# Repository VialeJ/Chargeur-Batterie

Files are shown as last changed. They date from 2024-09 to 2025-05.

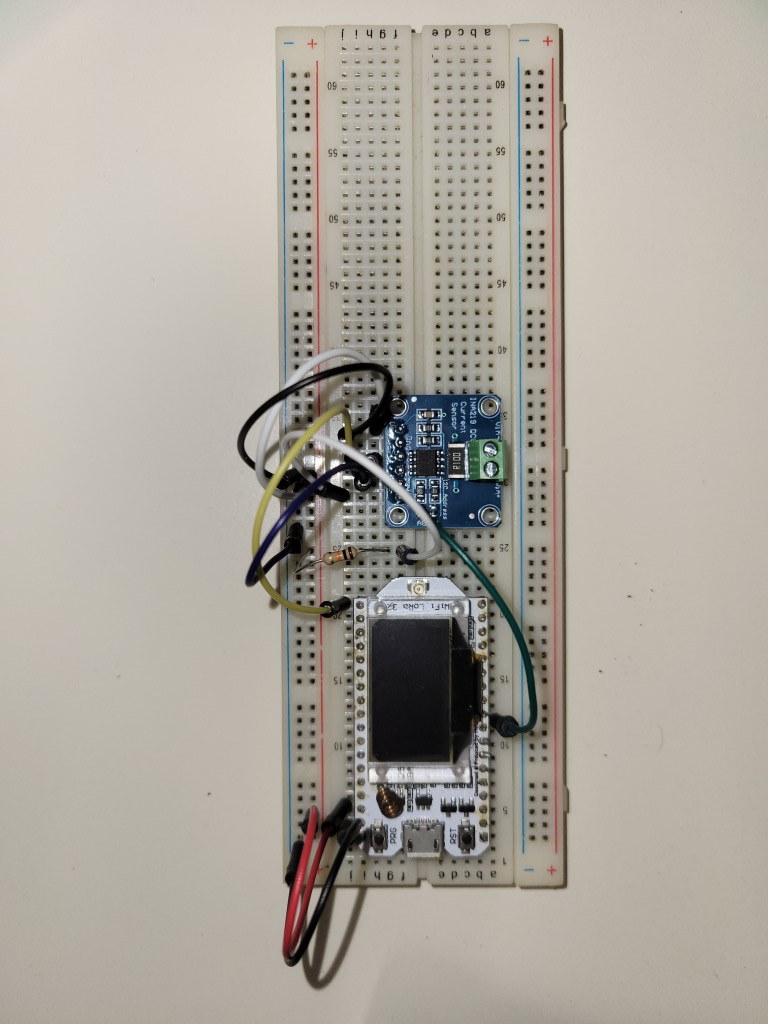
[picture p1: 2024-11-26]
Jeremie/Comptes-rendu/images/20241126_081917_Moyenne.jpg

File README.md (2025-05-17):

# Développement d'un chargeur de batterie

## 1 Cellule entre 5 et 7 Ah
- Posibilité de pouvoir gérer deux cellules dans un second temps

## Différents types de batterie 
- Li-ion (3.6V nom.)
- LiPo (3.7V nom.)
- LiFePO4 (3.2V nom.)

## Systèmes de protection
Protège la cellule contre les surtensions, les soustensions et la chaleur
(Les cellules li-ion utilisées dans ce projet contiennent déjà un BMS)

## Fuel gauge en I2C
Permet la communication des informations de charge et de décharge à un MCU

## 3 types d'alimentation possible:
- USB (5V)
- 12V
- Depuis un panneau solaire 26V (on prendra un Vin max de 28V)

## Package des composants
- CMS
- Eviter un boitier BGA

## Courant de charge de 1A max

## Obtenir le coût le plus faible
Le but est de pouvoir rendre le système reproductible 

## Références des composants
- Ajout de la Datashette des composants utilisés dans le repo git

## Travail à faire :
- Etudier circuits intégrés existants pour la cherge et la fuel gauge et choisir
- INA219 : Mesure de tension, courant et puissance
- Documentation

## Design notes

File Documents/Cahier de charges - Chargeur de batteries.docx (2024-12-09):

# Projet Electronique

# Chargeur de batteries

Cahier des Charges

# Introduction

L’objectif du projet est de créer un chargeur de batterie suivant les caractéristiques énoncées dans ce cahier des charges. Cela permettra d’exploiter des technologies tel que les batteries au lithium, la communication I2C, la gestion d’alimentation ou la conception de schéma électronique.

# Contraintes techniques

## Caractéristiques de la batterie à charger

Pour ce projet, nous utiliserons une cellule de type Lithium-Ion (li-ion) et Lithium-Polymère (LiPo). Il sera par la suite possible d’intégrer la gestion des cellules Lithium Fer Phosphate (LiFePo4) à notre projet. De plus, une piste d’amélioration possible est d’ajouter une cellule à charger à notre projet pour un total de deux cellules en charge en parallèles.

Nous ciblons des cellules d’une capacité comprise entre 5 et 7 Ampères heures (Ah).

Voici une courte description de chaque type de cellules utilisées pour ce projet :

### 1. Li-ion (Lithium-ion)

- Tension : 3,6V nominale, charge jusqu'à 4,2V.
- Méthode de charge : Charge en deux étapes CC-CV (courant constant puis tension constante).
- Avantages : Haute densité énergétique, recharge rapide.
- Inconvénients : Sensible à la surcharge, risque de surchauffe.
- Protection en charge : Utilisation d’un BMS (Battery Management System) pour couper le courant une fois la charge complète atteinte et éviter les surcharges.

### 2. LiPo (Lithium Polymère)

- Tension : 3,7V nominale, charge jusqu'à 4,2V.
- Méthode de charge : Technique CC-CV avec surveillance constante, sensible aux variations.
- Avantages : Légèreté et flexibilité de forme, haute densité énergétique.
- Inconvénients : Fragile, risque de gonflement ou d’inflammation en cas de surcharge.
- Protection en charge : Surveillance renforcée pour maintenir le courant et la tension dans des limites sûres.

### 3. LiFePO4 (Lithium Fer Phosphate)

- Tension : 3,2V nominale, charge jusqu’à 3,65V.
- Méthode de charge : Technique CC-CV, seuils de tension inférieurs à ceux des autres lithiums.
- Avantages : Excellente stabilité thermique, longue durée de vie même sous charge répétée.
- Inconvénients : Densité énergétique plus faible.
- Protection en charge : Le BMS surveille la charge pour éviter toute surcharge, bien que le risque thermique soit faible.

## Modes d’alimentation

Le projet disposera de plusieurs modes d’alimentation distincts, permettant une certaine flexibilité à l’utilisateur. Il faut veiller à fournir la puissance nécessaire à notre circuit pour alimenter nos composants et charger notre cellule. Le courant de charge imposé est de 1A par cellule.

Le chargeur de batterie devra disposer :

- D’une alimentation par USB : Mode d’alimentation 5V, un port USB à définir permettra une connexion plus universelle et simplifiée à notre projet. Attention tout de même à fournir la puissance nécessaire pour charger la cellule et alimenter notre système.
- D’une alimentation par panneau solaire : Un panneau solaire doit pouvoir être connecté à notre système, ainsi nous pourrons charger nos batteries en journée. La tension maximale délivrée par le panneau solaire est de 28V. Il faut prendre garde à la variation de la tension au cours de la journée.
- D’une alimentation par 12V : Une alimentation externe de 12V doit aussi pouvoir être connectée à notre chargeur de batterie.

## Protection et contrôle

Le projet devra intégrer un système de contrôle d’état de la charge, pour cela on utilisera un fuel gauge connectée en I2C à une carte ESP32 intégrant un écran. Ainsi nous pourrons contrôler, le courant de charge, le taux de charge et la tension de la cellule. Ce composant ouvrira de nouvelles possibilités telles qu’afficher le temps depuis lequel la cellule charge ou le temps restant.

Pour ce qui est de la partie protection, les cellules lithium étant des cellules très sensibles, il faut un système fiable et capable de prévenir d’éventuels problèmes. Dans notre cas, nous devrons utiliser un composant de gestion de charge qui sera capable de :

- Protéger notre cellule contre la surcharge en interrompant la charge lorsque la tension maximale est atteinte.
- Protéger notre cellule contre la surintensité pour éviter les courants excessifs.
- Permuter les modes de charges au bon moment (passer d’une charge en courant constant à une charge en tension constante).
- Possibilité d’ajouter un contrôle de la température pouvant nous aider à couper la charge en cas de surchauffe.

## Exigences Techniques

Composants CMS principalement :

- La plupart des composants du chargeur devront être en technologie CMS (Composants Montés en Surface) afin de minimiser l’encombrement du circuit, simplifier l’assemblage et réduire les coûts de fabrication.

Exclusion des boîtiers BGA :

- Les composants utilisant des boîtiers BGA (Ball Grid Array) devront être évités en raison des défis liés à leur assemblage et à leur accessibilité au cas où nous souhaiterions réaliser des mesures.

## Contraintes de Conception

Coût minimal :

- Le chargeur devra être conçu de manière à minimiser le coût global tout en respectant les exigences techniques et fonctionnelles.
- Les choix des composants et des matériaux devront favoriser les alternatives low-cost, sans compromettre la sécurité et la qualité.

Reproductibilité :

- Le système doit être conçu pour être reproductible à grande échelle, avec des composants faciles à trouver sur le marché et une documentation claire pour l'assemblage et l’utilisation.
- La conception devra être modulaire et flexible, permettant des modifications ou améliorations futures sans révision complète.

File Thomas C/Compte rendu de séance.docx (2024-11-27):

# Compte rendu de séance

WATTY BATTERY

Thomas Cougouluegne

Séance 1: Choix des groupes, Discussion du contenu du cahier des charges et limites du projet.

Séance 2: Définition en groupe du cahier des charges du projet, définition des sujets de travail de chacun, recherches sur le fonctionnement et les valeurs critiques des circuits fuel gauge.

Séance 3: Recherche de composant fuel gauge, et comparaison des options disponibles.

Recherche arrêtée sur le TI BQ27411DRZT-G1A ;

Boitier 12 VDFN disponibles, soudable sans soucis à la main, 1 cellule,

Tech Li-ion, communication des données en I²C.

Question de la charge d’éléments en parallèle ; attention au déséquilibrage de lignes. Pose la question du besoin d’un équilibreur de ligne ? Après révision des fonctions du circuit de charge, l’équilibrage de lignes sera maitrisé par le circuit.

Séance 4: Lecture et création du schéma avec les recommandations de Texas Instrument pour

le BQ27411. Uniquement deux condensateur a mettre en place autour du CI

(entre Vdd et Vss / entre BAT et Vss).

Mettre en place le système de detection de batterie. Quand une batterie est en charge, la pin BIN doit recevoir un signal à l’état bas (environ 0V). Pour ce, système de pull-up à Vdd de la pin BIN (1,8 MOhms) et connexion a la sortie de la batterie via thermistance pour qu’à la connexion de la batterie la pin BIN soit pull-down. (10kOhms).

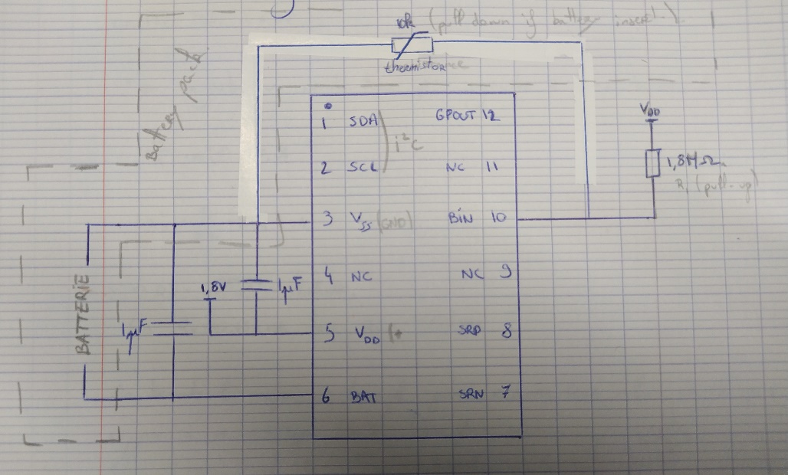
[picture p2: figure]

Possible besoin d’un régulateur de tension à 1.8V pour l’alim de la fuel gauge.

Vu voltag reg chez les distribs, disponibles à l’unité a faible cout, verifier si diode ou voltage divider possible (attention stab si V div).

Début du schéma sous kicad pour mise en commun et commande.

Séance 5 :

Schéma fait sous kicad et révisé, pin BIN réajustée selon notre besoin.

Recherche de régulateur de tension pour le schéma Circuit de charge.

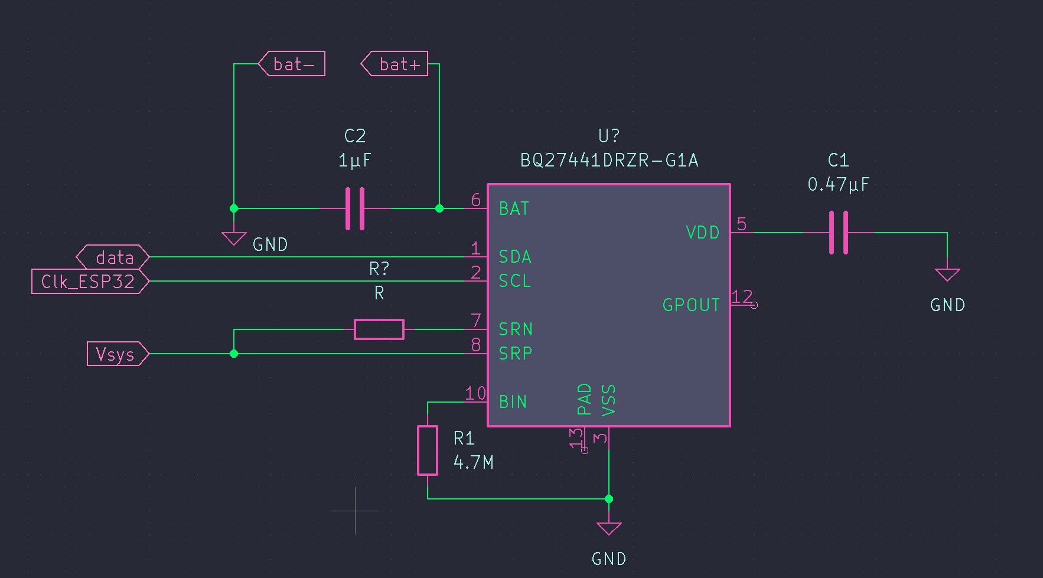
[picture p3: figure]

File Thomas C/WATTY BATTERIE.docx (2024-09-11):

30V -> buck -> 5V LMxxxx

12V -> buck -> 5V Même buck pour 30V et 12V ? (verif si pb quand 30 et 12 actifs simultané)

5V -> 5V

Trames I2C pour communiquer « fuel gauge » et « tension de sortie de panneau »

Pour gestion I2C, MCU mieux que

Protection court-circuit sera donné par M.Peter dans les prochaines séances. (a mettre en serie avec la sortie vers batterie)

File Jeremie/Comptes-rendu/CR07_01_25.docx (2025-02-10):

On fait quoi ?

Rédaction d’un protocole de test pour le chargeur

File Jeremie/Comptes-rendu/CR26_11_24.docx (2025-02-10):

Changement de board sur Arduino IDE pour régler le problème (Pas la bonne séléctionnée au préalable). Le programme s’upload sur la carte

Le pinout utilisé est le suivant

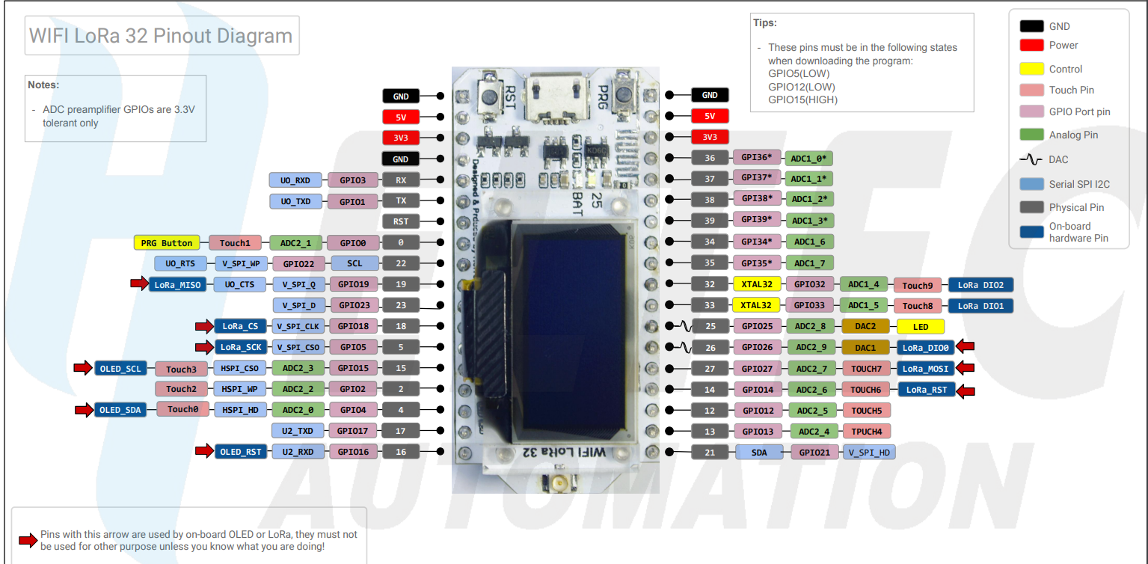
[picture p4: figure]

Tests : On branche une résistance de 10kOhm en série pour effectuer des tests, comme ceci :

La ligne + est reliée au 3.3V, la ligne – au GND. La résistance va au Vin+, le Vin- va au GND. SDA et SCL sont connectés à leurs branches respectives.

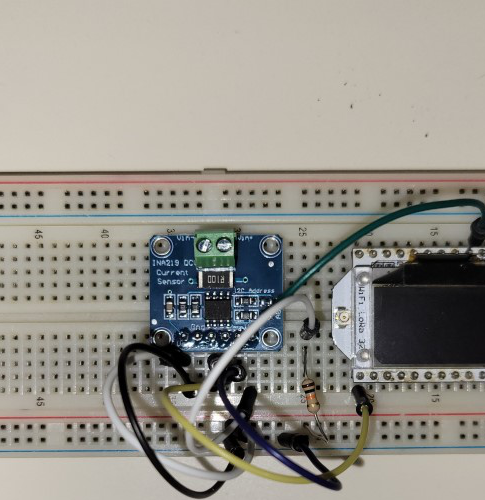
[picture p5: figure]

On obtient en mesures avec le code getinfos :

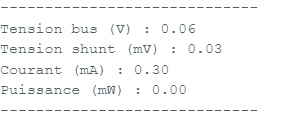
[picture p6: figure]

Ce qui semble cohérent comme on a placé la resistance avant le capteur.

En changeant son emplacement, connectant la résistance au GND, on obtient :

Ce qui est aussi cohérent, comme on mesure la tension aux bornes de la résistance.

On peut faire un simple pont diviseur pour vérifier plus concrètement :

Avec deux résistances de 10kOhm, le courant semble trop faible pour que le capteur le detecte correctement. On met alors des résistances plus faibles pour augmenter le courant. Avec deux résistances de 1kOhm, on obtient :

Ce qui est cohérent avec les valeurs de résistances et de la tension envoyée. On envoie 3.3 depuis l’ESP dans un pont diviseur entre deux résistances de 1kOhm, donc ~1.5V aux bornes de chaque résistance

Amélioration du code pour interroger la fuel gauge (Quand on l’aura reçue), sur l’état de charge et le votlage.

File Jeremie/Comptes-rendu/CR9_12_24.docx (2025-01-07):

Recherches CN3761

Input range : 4.5V – 28V

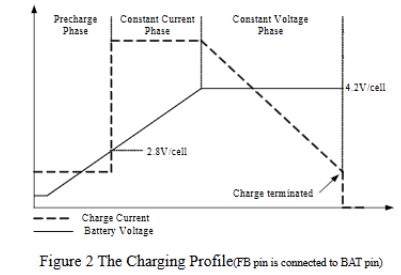
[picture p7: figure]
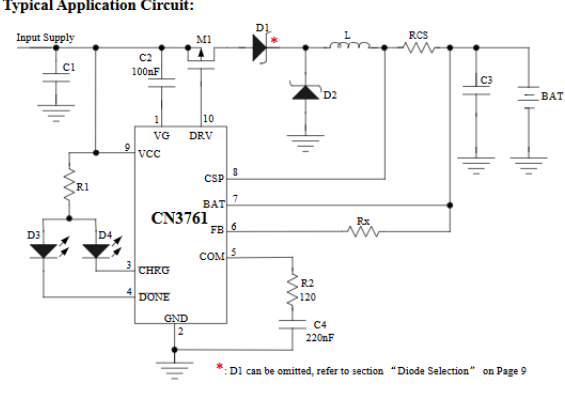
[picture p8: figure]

DS6521 : Max input voltage à 24V donc on l’exclut des possibilités de régulateur de charge

Optimisation du temps

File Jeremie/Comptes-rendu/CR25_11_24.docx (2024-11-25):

25/11/24 : Création d’un premier code de test, branchements de l’esp sur bread-board

Problème d’upload du programme sur l’esp

Branché au PC, la plaque n’explose pas, ce qui est un point positif.

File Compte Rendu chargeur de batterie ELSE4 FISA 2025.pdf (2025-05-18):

Faucherre Thomas
Cougouluegne Thomas
Viale Jérémie

# Projet Electronique Chargeur de batteries

# Introduction :

L’objectif du projet est de créer un chargeur de batterie suivant les caractéristiques énoncées dans ce cahier des charges joint. Cela permettra d’exploiter des technologies telles que les batteries au lithium, la communication I2C, la gestion d’alimentation ou la conception de schéma électronique.

# Cahier des charges :

## Contraintes techniques

### Caractéristiques de la batterie à charger

Pour ce projet, nous utiliserons une cellule de type Lithium-Ion (li-ion) et Lithium-Polymère (LiPo). Il sera par la suite possible d’intégrer la gestion des cellules Lithium Fer Phosphate (LiFePo4) à notre projet. De plus, une piste d’amélioration possible est d’ajouter une cellule à charger à notre projet pour un total de deux cellules en charge en parallèle.

Nous ciblons des cellules d’une capacité comprise entre 5 et 7 Ampères heures (Ah).

Voici une courte description de chaque type de cellules utilisées pour ce projet :

1. Li-ion (Lithium-ion)
- Tension : 3,6V nominale, charge jusqu'à 4,2V.
- Méthode de charge : Charge en deux étapes CC-CV (courant constant puis tension constante).
- Avantages : Haute densité énergétique, recharge rapide.
- Inconvénients : Sensible à la surcharge, risque de surchauffe.
- Protection en charge : Utilisation d’un BMS (Battery Management System) pour couper le courant une fois la charge complète atteinte et éviter les surcharges.

2. LiPo (Lithium Polymère)
- Tension : 3,7V nominale, charge jusqu'à 4,2V.
- Méthode de charge : Technique CC-CV avec surveillance constante, sensible aux variations.
- Avantages : Légèreté et flexibilité de forme, haute densité énergétique.
- Inconvénients : Fragile, risque de gonflement ou d’inflammation en cas de surcharge.
- Protection en charge : Surveillance renforcée pour maintenir le courant et la tension dans des limites sûres.
3. LiFePO4 (Lithium Fer Phosphate)
- Tension : 3,2V nominale, charge jusqu’à 3,65V.
- Méthode de charge : Technique CC-CV, seuils de tension inférieurs à ceux des autres lithiums.
- Avantages : Excellente stabilité thermique, longue durée de vie même sous charge répétée.
- Inconvénients : Densité énergétique plus faible.
- Protection en charge : Le BMS surveille la charge pour éviter toute surcharge, bien que le risque thermique soit faible.

### Modes d’alimentation

Le projet disposera de plusieurs modes d’alimentation distincts, permettant une certaine flexibilité à l’utilisateur. Il faut veiller à fournir la puissance nécessaire à notre circuit pour alimenter nos composants et charger notre cellule. Le courant de charge imposé est de 1A par cellule.

Le chargeur de batterie devra disposer :

- D’une alimentation par USB : Mode d’alimentation 5V, un port USB à définir permettra une connexion plus universelle et simplifiée à notre projet. Attention tout de même à fournir la puissance nécessaire pour charger la cellule et alimenter notre système.
- D’une alimentation par panneau solaire : Un panneau solaire doit pouvoir être connecté à notre système, ainsi nous pourrons charger nos batteries en journée. La tension maximale délivrée par le panneau solaire est de 28V. Il faut prendre garde à la variation de la tension au cours de la journée.
- D’une alimentation par 12V : Une alimentation externe de 12V doit aussi pouvoir être connectée à notre chargeur de batterie.

### Protection et contrôle

Le projet devra intégrer un système de contrôle d’état de la charge, pour cela on utilisera un fuel gauge connectée en I2C à une carte ESP32 intégrant un écran. Ainsi nous pourrons contrôler, le courant de charge, le taux de charge et la tension de la cellule. Ce composant ouvrira de nouvelles possibilités telles qu’afficher le temps depuis lequel la cellule charge ou le temps restant.

Pour ce qui est de la partie protection, les cellules lithium étant des cellules très sensibles, il faut un système fiable et capable de prévenir d’éventuels problèmes. Dans notre cas, nous devrons utiliser un composant de gestion de charge qui sera capable de :

- Protéger notre cellule contre la surcharge en interrompant la charge lorsque la tension maximale est atteinte.
- Protéger notre cellule contre la surintensité pour éviter les courants excessifs.
- Permuter les modes de charges au bon moment (passer d’une charge en courant constant à une charge en tension constante).
- Possibilité d’ajouter un contrôle de la température pouvant nous aider à couper la charge en cas de surchauffe.

## Exigences Techniques

Composants CMS principalement :

- La plupart des composants du chargeur devront être en technologie CMS (Composants Montés en Surface) afin de minimiser l’encombrement du circuit, simplifier l’assemblage et réduire les coûts de fabrication.

Exclusion des boîtiers BGA :

- Les composants utilisant des boîtiers BGA (Ball Grid Array) devront être évités en raison des défis liés à leur assemblage et à leur accessibilité au cas où nous souhaiterions réaliser des mesures.

## Contraintes de Conception

Coût minimal :

- Le chargeur devra être conçu de manière à minimiser le coût global tout en respectant les exigences techniques et fonctionnelles.
- Les choix des composants et des matériaux devront favoriser les alternatives low-cost, sans compromettre la sécurité et la qualité.

Reproductibilité :

- Le système doit être conçu pour être reproductible à grande échelle, avec des composants faciles à trouver sur le marché et une documentation claire pour l'assemblage et l’utilisation.

La conception devra être modulaire et flexible, permettant des modifications ou améliorations futures sans révision complète.

Maintenant que le contexte global du projet est posé, nous pouvons commencer à détailler chaque partie, en commençant par le circuit de gestion de charge, puis le circuit d’alimentation, et terminer par la gestion du code permettant de valider le fonctionnement de notre chargeur.

# Partie Circuit de gestion de charge :

Cette partie concerne le choix et le design de l’écosystème autour du composant principal de notre projet. Ce circuit a pour but la régulation de la tension et du courant de charge de la batterie. A noter que ce composant ne gère pas la décharge de la batterie, l’utilisateur pourra se brancher directement sur les bornes de la batterie. D’après le cahier des charges, nous voulons un composant qui peut prendre en entrée une tension maximale de 28V (adapté au solaire), chargé notre batterie à 1 A maximum, charger une seule cellule et gérer dans un premier temps la charge des cellules lithium ion et lithium polymère.
Pour sélectionner le bon composant en fonction des caractéristiques du cahier des charges, nous avons utilisé un tableau comparatif des références de composant trouvées sur internet.

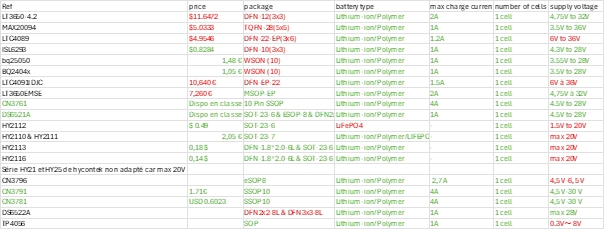
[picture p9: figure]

Figure 1 - Tableau comparatif des circuits de charge

Cette méthode nous permet selon nos critères de choisir correctement notre circuit. La principale contrainte est la tension d’entrée maximum de 28V. En conclusion de ce tableau, nous avons retenu deux circuits : le DS6521 et le CN3761. Ces composants ont l’avantage d’être disponibles en salle de cours.
Nous avons donc choisi le DS6521 de chez DSTECH, ce circuit est dans un package ESOP-8 ce qui respecte la contrainte de package CMS non BGA. Ce circuit possède les caractéristiques suivantes :
- Tension d'entrée de 28V ; avec protection contre les surtensions à 6V
- Précision de la tension de charge à 1 %
- Courant de charge programmable de 50 mA à 1 A
- Régulation thermique à 125°C
- Courant de fin de charge programmable de 5 mA à 100 mA
- Courant de précharge fixe à ISET / 10
- Fonctionnement conforme à la plage JEITA via NTC batterie – 1/2 du courant de charge rapide à froid, et 4,05 V à chaud
- Courant de fuite de la batterie très faible : 0,1 µA
- Fonction de protection contre la connexion inversée de la batterie

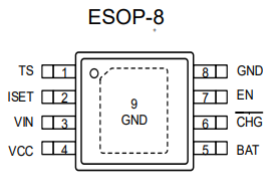
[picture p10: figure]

Figure 2 - Package et brochage du DS6521

Il nous a ensuite fallu réaliser le schéma autour de ce composant. Pour cela nous allons nous inspirer du schéma fourni par le fabricant dans la datasheet :

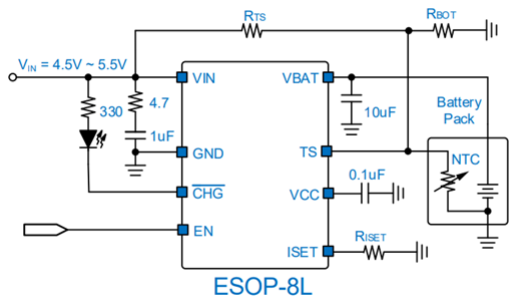
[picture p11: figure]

Figure 3 - Schéma classique

Dans un premier temps, nous utilisons un filtrage à l’entrée Vin : la résistance de 4,7 Ω et le condensateur de 1 µF forment un filtre RC qui stabilise la tension d’entrée. La résistance limite les courants d’appel lors de la mise sous tension. Le condensateur filtre les bruits et pics de tension parasites. Ensemble, ils protègent le circuit et assurent une alimentation plus propre. Ce montage améliore la fiabilité du système.
La broche CHG barre est à l’état haut lorsque la batterie ne charge pas, et passe à l’état bas lorsque la batterie charge. Contrairement au design recommandé, nous n’allons pas placer la led avec la résistance de 330 Ohm sur l’entrée Vin, mais plutôt sur la broche VCC. Le VCC du DS6521 est une source de tension 5V, ainsi si la tension d’entrée varie la résistance sera toujours bien dimensionnée car positionnée sur le VCC de 5V.

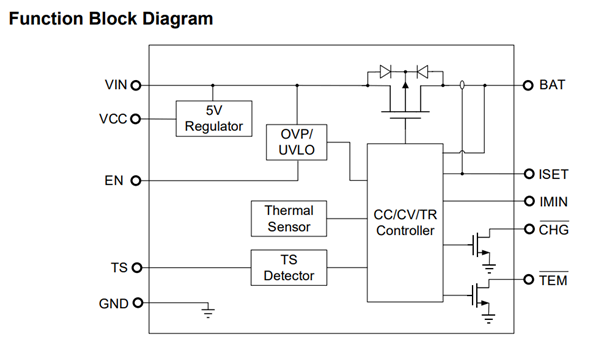
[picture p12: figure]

Figure 4 - Diagramme bloc du DS6521

La broche EN sert à l’activation du circuit, on la met à 5V lorsqu’on veut activer le circuit, cependant nous voulons toujours activer le DS6521 donc nous allons relier ce pin au 5V du VCC.
La broche ISET régule de courant de charge selon ces équations :

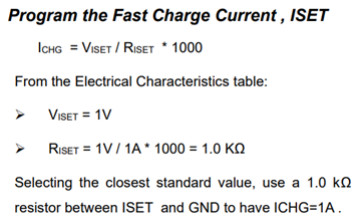
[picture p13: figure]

Figure 5 - calcul de ISET

Ainsi nous souhaitons une charge de 1A, donc nous allons utiliser une résistance de 1kOhm pour ce projet. Pour la phase de test, nous utilisons une batterie de plus faible capacité et donc avec un courant de charge réduit, ainsi nous allons diviser par trois cette charge (330 mA) donc nous utiliserons selon les calculs une résistance 3 fois plus grande (soit 3 kOhms).
Pour la partie gestion de température, notre projet intègre des capteurs de températures qui permettent de monitorer la charge. Deux capteurs seront présents, un sur le DS6521 pour gérer la charge, et un sur le circuit fuel gauge qui permettra d’avoir une surveillance de la température en temps réel lors de la décharge. Pour la partie DS6521, la broche TS est réservée à l’utilisation d’une thermistance (NTC) qui est une résistance variant avec la différence de température. Voici les caractéristiques de la datasheet sur le capteur de température :

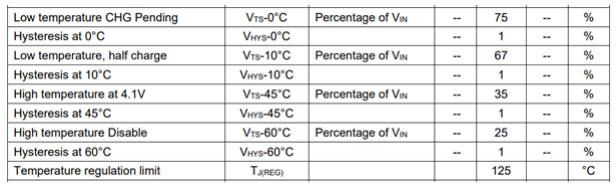
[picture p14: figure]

Figure 6 - NTC caractéristiques en tension

La température est détectée en fonction du rapport de la tension TS sur la tension d’entrée Vin. Ainsi, nous avons besoin de créer un pont diviseur comme indiqué dans le schéma type du constructeur. Dans le tableau plus haut on remarque que la température normale d’utilisation est atteinte pour 50% de Vin en moyenne, il faut donc diviser par deux Vin, pour cela on va réaliser un pont diviseur de tension avec comme indiqué dans le schéma plus haut RBOT à 10kOhm (en parallèle de la NTC) et donc une résistance RTS équivalente à la NTC et RBOT en parallèle, soit 5 kOhms. Ainsi pour la température moyenne d’utilisation on est à 50% de Vin.
On notera d’après la datasheet qu’en dessous de 0°C (VTS>0.75Vin) la charge se coupe et se met en attente, entre 0 et 10°C (0.67Vin<VTS<0.75Vin) on charge avec un courant divisé par deux, entre 45°C et 10°C (0.35Vin<VTS<0.67Vin) on est en mode de charge normal, entre 45°C et 60°C (0.25Vin<VTS<0.35Vin) on charge à 4.1V au lieu de 4.2V et enfin au-dessus de 60°C (VTS<0.25Vin) On désactive de circuit intégré.
On ajoute aussi des condensateurs en entrée (sur Vin en série avec une résistance) et sur les pins d’alimentation tel que CVV et Bat+. Ces Condensateurs servent au filtrage des potentielles parasites de tensions ainsi qu’au découplage des sources d’énergies, c’est-à-dire qu’ils prennent le relais comme source de tension lors des forts appels de courant.

Voici finalement notre version du schéma du DS6521 et de son écosystème :

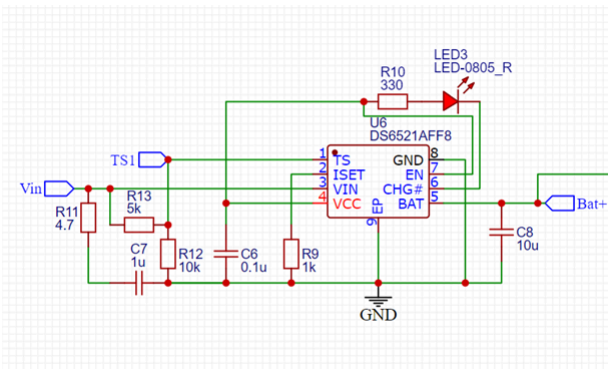
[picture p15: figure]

Figure 7 - Notre schéma du DS6521

Après de nombreux tests sur notre circuit, il s’est avéré que nous avons commis une erreur dans le choix du composant de charge. En effet l’intitulé de la datasheet semble trompeur. Il y est mentionné une tension d’entrée de 28V, mais ce n’est en réalité pas le cas.

Figure 8 - Intitulé datasheet DS6521

Figure 9 - Extrait des caractéristiques du DS6521

La datasheet est une version chinoise traduite en anglais, ce qui peut être la source de l’erreur, mais ici le DS6521 fonctionne jusqu’à 6V en entrée et est protégé pour les surtensionsjusqu’à 28V. Cela rend notre projet inapte pour les conceptionsalimentée par panneau solaire, et donc lui fait perdre son intérêt principal. Cependant nous pouvons tout de même réaliser des tests avec des tensions de 5V.

# Partie Circuit Fuel Gauge :

Cette partie concerne le choix et le design de l’écosystème autour du composant fuel gauge de notre projet. Ce circuit a pour but de mesurer l’énergie dans la batterie afin de superviser la batterie de manière cohérente.
De nombreuses solutions fuel gauge sont aujourd’hui disponibles sur le marché, toutefois le cahier des charges implique de trouver une solution gérant les technologies LiPO, Li-ion, . Mon premier choix s'est alors porté sur le Texas instrument BQ25441-G1 qui est une solution dimensionnée pour notre type d’application single-cell sans trop de surplus. Toutefois, ce composant n’étant disponible que dans les packages VSON (pitch de 0,4mm), cette solution à été abandonnée car jugée trop difficile à monter sur le pcb.

Alors après de longues recherches infructueuses pour trouver un composant équivalent correspondant au critère de pitch et package, nous nous sommes résiliés à utiliser le Texas instrument BQ34Z100-G1. Composant fuel gauge plus avancé pour n-cell (Li-ion, LiFePO4, et plus) qui malgré son surdimensionnement est un des rares seul présentant toutes les caractéristiques recherchées.

Les fonctions utiles pour nous seront :

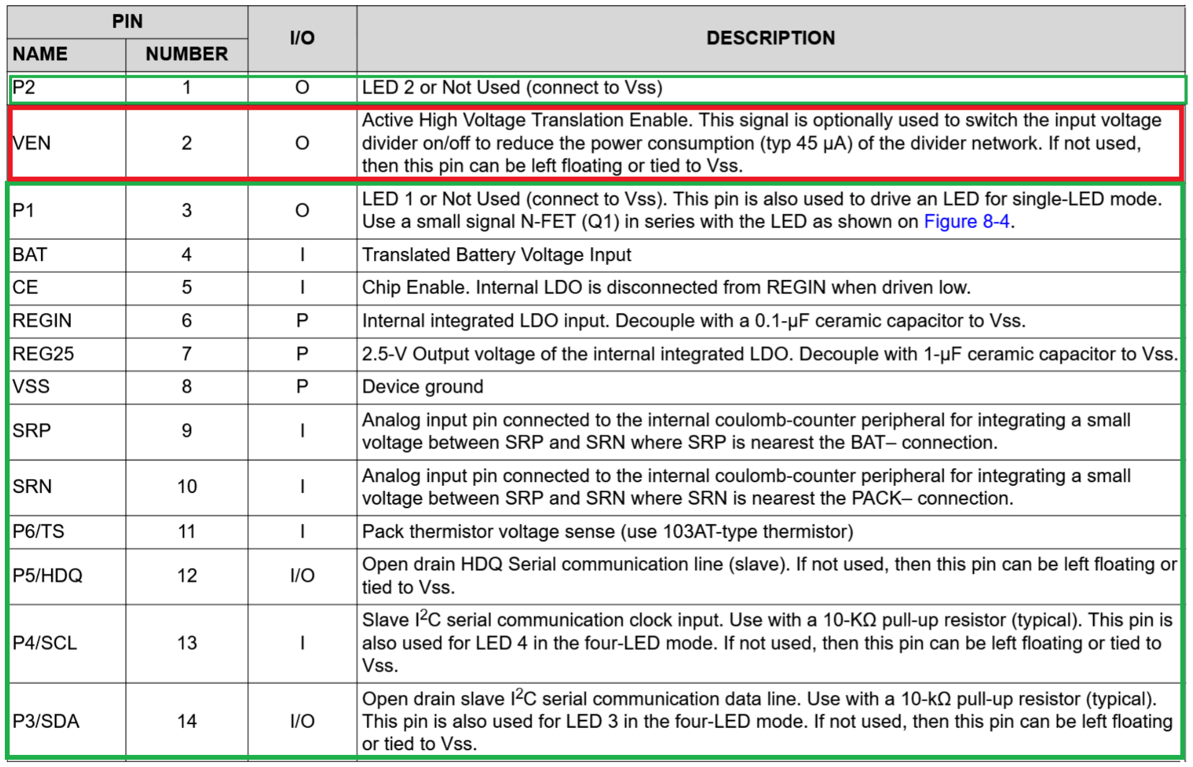
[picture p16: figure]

Figure 10 - Fonctions utiles Fuel Gauge (encadrées en vert)

Il faut donc dans notre schéma intégrer les composants nécessaires au bon fonctionnement de ces dernières tels que :

1. Le montage de R1; R2; U2 -> permet de pull-up SDA à 3.3V
Sachant que 3.3V ne sont présents nulle part ailleurs sur le schéma pour un pull-up direct, d’où la mise en place de ce level converter.
Rappel: pour fonctionner tout bus I²C doit être par défaut à 3.3V et communique en changeant l’état de la ligne via pull-downs.
2. Le montage de R3; R4; U1 -> permet de pull-up à 3.3V SCL comme 1.
3. Le montage de U3; U4; R8; R14 -> permet l’allumage de LEDs de fonctionnement contrôlées par les signaux P1 et P2.
Les résistances sont dimensionnées pour maîtriser le courant nécessaire aux LEDs. Quant aux deux MOS ils permettent de mettre à la masse (ou non) la branche du circuit dont P1 ou P2 est actif pour allumer (ou éteindre) la LED en conséquence.
4. C1 et C2 -> Sont des capacités de découplage qui pour rappel servent à réduire les bruits et interférences dans un circuit.
5. Le montage de R5; R6; R7; C3; C4; C5 -> Permet de transmettre une image des caractéristiques de la batterie à nos pins SRN et SRP.
C’est ce montage qui permet à notre fuel gauge de fonctionner.
R5 est une résistance de shunt
6. R6; R7; C3; C4; C5 forment un filtre passe bas (différentiel) qui permet de réduire les impuretés et bruits sur le signal. Les valeurs sont données par le constructeur.
Il faut que ce montage soit routé avec des pistes différentielles
(de même longueur et propriétés) pour soigner le signal et assurer des valeurs reçues cohérentes. Pour plus de détails voir pages 55 et 56 de la datasheet.

Notre schéma final est donc le suivant :

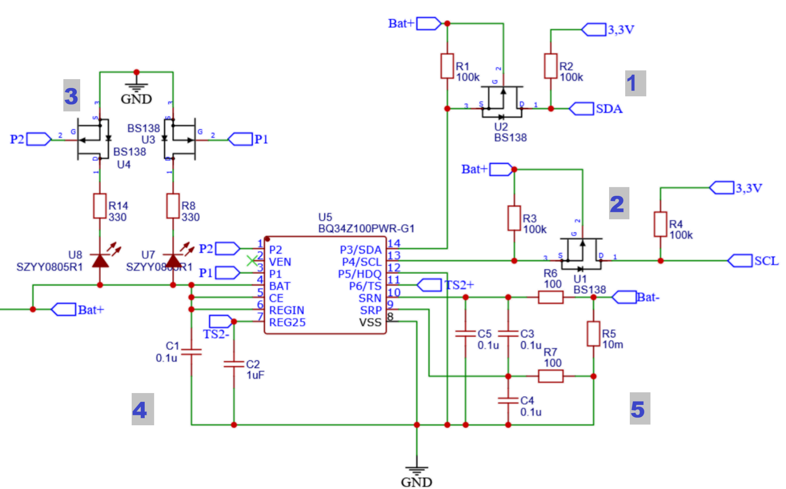
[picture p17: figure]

Figure 11 - Schéma Fuel Gauge

Après les tests sur notre solution la partie fuel gauge marche comme prévu et communique bien en I²C les valeurs nécessaires. Rien ne semble à retoucher sur cette partie.

# Partie codage et tests :

Cette parti concerne l’agencement du code et des fonctionnalités choisies pour valider le fonctionnement du système, il est fait sous arduino et doit fonctionner avec une carte HELTEC Wifi-LoRa v1.
La carte Heltec doit rêtre reliée à un capteur INA-219 et la fuel-gauge précisée dans le chapitre précédent via I2C, donc il est dans un premier temps important d’identifier les broches à utiliser dans ce but :

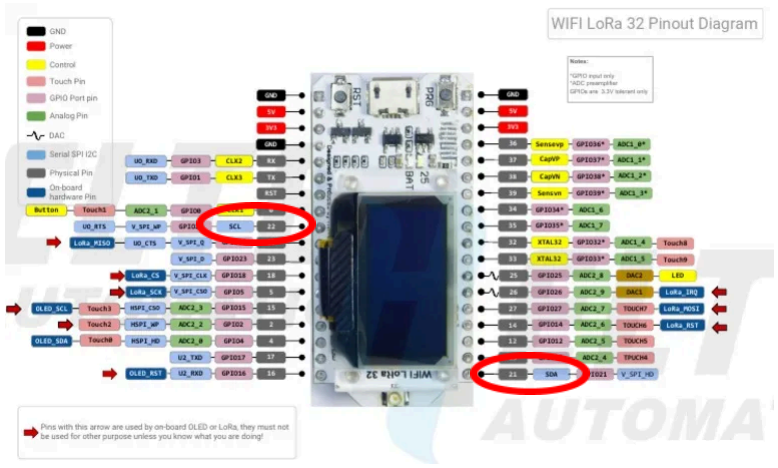
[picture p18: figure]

Figure 12 - Pinout de la carte HELTEC WIFI LoRa 32 v1

Nous utiliserons dans le futur les broches mises en évidence sur la figure 12 pour la communication en I2C.
Passons à la revue du code :
Déclaration des bibliothèques et constantes du programme :
Dans cette partie, on prend deux bibliothèques, Wire, qui est la bibliothèque I2C classique d’Arduino, et une pour l’INA, fournie par Adafruit, qui évite de devoir créer les fonctions d’interrogation de l’INA-219 à la main. Aucune bibliothèque n’est disponible pour la fuel-gauge BQ34Z110, donc pour celui là, il a fallu, dans la datasheet, rechercher quels registres interroger pour obtenir les données voulues.
Plusieurs constantes sont définies pour faciliter l’interrogation de la fuel gauge : les adresses des registres d’état de charge, de tension et de température sont extraites de la documentation du BQ34Z110. Une constante permet aussi d’activer ou non les messages de debug. Deux intervalles de temps sont ensuite définis pour gérer de manière non bloquante la fréquence des mesures : 1000 ms pour le courant et 5000 ms pour les autres données de la fuel gauge. Des variables previousMillis permettent de suivre le temps écoulé.

Fonction sendControlCommand :
Cette fonction permet d’envoyer une commande de contrôle à la fuel gauge via le registre Control() (adresse 0x00). Par exemple, elle est utilisée ici pour envoyer la commande IT_ENABLE (0x0021) qui active le suivi d’impédance. La commande est envoyée en little endian (LSB puis MSB), comme spécifié dans la datasheet. Un message est affiché en mode debug pour confirmer l’envoi.
Cette fonction est utile pour calibrer la fuel gauge, dans un premier cycle de charge/decharge contrôlé, afin qu’elle renvoie des valeurs d’état de charge cohérentes.

Fonctions de lecture I2C :
Deux fonctions sont définies pour lire des données depuis la fuel gauge : readFuelGaugeByte() lit un seul octet (utilisé pour l’état de charge).
readFuelGaugeWord() lit deux octets en little endian (utilisé pour la tension et la température).
Chacune vérifie s’il y a eu une erreur de transmission ou un nombre de données insuffisant. En cas de problème, une valeur d’erreur est renvoyée et un message est affiché si le mode debug est activé.

Fonction updateFuelGauge :
Cette fonction regroupe les différentes lectures de la fuel gauge :
Elle lit l’état de charge (en %), la tension (en millivolts) et la température (en dixièmes de kelvin, convertie ensuite en °C).
Chaque mesure est affichée sur le port série si elle est valide, sinon un message d’erreur est montré.
Une ligne de séparation est imprimée à la fin pour plus de lisibilité.

Fonction setup :
Le port série est initialisé, puis le bus I2C est activé via Wire.begin().
Le capteur INA219 est initialisé à l’aide de la méthode begin() fournie par la bibliothèque Adafruit. En cas d’échec, le programme s’arrête. Sinon, un message confirme la réussite. Après un court délai de stabilisation, la commande IT_ENABLE est envoyée à la fuel gauge pour démarrer la mesure d’impédance.

Fonction loop :
La fonction principale du programme repose sur deux mises à jour non bloquantes, basées sur la fonction millis() :
Toutes les secondes, le courant mesuré par le capteur INA219 est affiché.
Toutes les cinq secondes, les données de la fuel gauge sont lues et affichées via updateFuelGauge().
Cela permet au programme de fonctionner sans pauses inutiles (sans delay()), ce qui est utile pour des systèmes embarqués réactifs.

Passons enfin à l’affichage des tests :

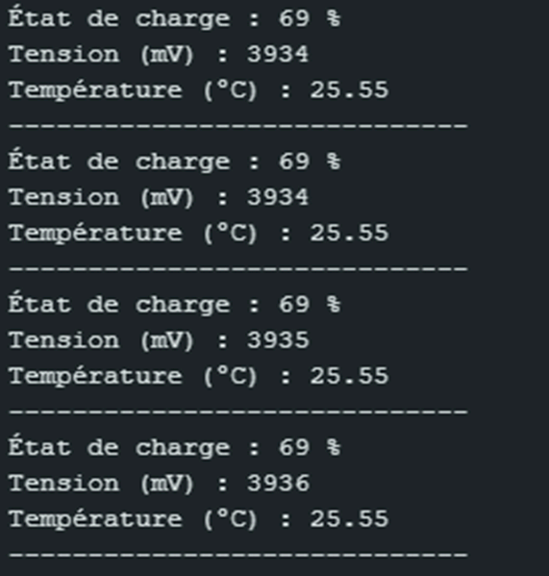
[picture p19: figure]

Figure 13 - Resultats Fuel Gauge

Voici les résultats de la communication avec la fuel Gauge, n’étant pas calibrée, elle renvoie une valeur de State Of Charge (SOC) fausse, mais cohérente, entre 0 et 100%, ce qui est encourageant. La valeur de tension et la température ont pu être confirmées respectivement avec un multimètre et des pointes, et avec un thermomètre.

Pour ce qui est de la communication avec l’INA-219, des tests ont été effectués au premier semestre pour valider le fonctionnement, tests ayant donné les résultats suivants :

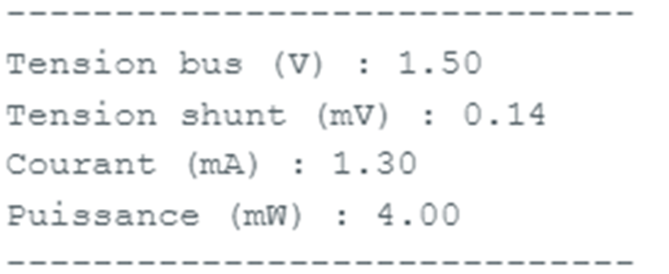
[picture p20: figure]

Figure 14 - Résultats INA-219

L’INA était monté pour mesurer la tension au milieu d’un pont diviseur de tension par 2, fait avec deux résistances de 1k ohm, alimenté par la broche 3.3V de la carte HELTEC, ce qui renvoie des valeurs cohérentes, bien que la valeur de courant semble un peu faible pour 3V qui passent dans 2k ohm, car on attend 1,5 mA, soit une erreur d’environ 13%.

# Pistes d’amélioration :

Notre projet n’a aujourd’hui pas encore la maturité nécessaire pour avoir un usage concret, il nous faut avant améliorer certains points notamment hardware. Voici une liste des points à améliorer :
- Circuit de charge non adapté : Comme précisé auparavant, le circuit de charge DS6521 possède une documentation ambiguë au niveau de sa tension de fonctionnement. Il nous faudra changer de circuit de charge pour en sélectionner un qui puisse fonctionner avec une tension d’entrée de 28V maximum pour respecter le cadre d’utilisation solaire.
- Pouvoir monter jusqu’à deux cellules Lithium : Ceci est un point d’amélioration qui a déjà été mentionné au début de notre projet, nous pourrions avoir la possibilité de charger deux cellules simultanément au lieu d’une seule (en série) pour avoir une plus grande tension de batterie (ce qui peut être utile dans le cadre de certains projets).
- Pouvoir utiliser la technologie LiFePo4 : Ce type de batterie n’est pas prise en charge par le DS6521, il faudrait donc changer de circuit de charge pour prendre en compte cet ajout.
- Protection supplémentaire de la batterie : A ce jour, nous utilisons des batteries Li-ion avec un BMS intégré, mais si nous voulions utiliser des cellules li-ion directement sans BMS, il faudrait alors ajouter un circuit supplémentaire de protection directement sur le projet (protection contre les surtensions, sous-tensions et court-circuit)
- Réaliser un cycle de charge/décharge complet avec le circuit fuel gauge : Ces circuits de mesure ont besoin d’une calibration, la charge et la décharge complète de la batterie n’a pas été faite faute de temps.
- Réaliser un protocole de test préalable, pour gagner du temps sur les dernières phases du projet

# Conclusion :

Le projet est bien avancé, le circuit de gestion de charge est à modifier, comme précisé dans la partie dédiée. Le CN3761 aura peut être plus de succès que le DS. Il faut toutefois bien lire les détails de datasheet ou faire des concessions pour avoir plus de facilités à trouver un composant.Notamment au niveau du pitch minimal des composants qui sont la contrainte majeur.
Il reste toutefois encore de la place pour l’amélioration, ce qui passera par plus de tests, la calibration de la fuel gauge et la modification du circuit de charge.

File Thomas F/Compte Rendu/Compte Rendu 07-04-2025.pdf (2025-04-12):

Compte Rendu 07/04/2025 :

Durant cette séance nous avons réalisé les tests de validation sur notre prototype.
Dans un premier temps nous avons pu confirmer que la tension d’alimentation de notre projet ne semble pas pouvoir dépasser 6V.
Nous approfondirons ce point durant la prochaine séance.
Pour l’instant, nous nous sommes concentrés sur les derniers réglages de notre projet ainsi que sur la partie test de la fuel gauge.
Nous avons vu comment décharger nos batteries dans une résistance d’une Trentaine de ohms pour ainsi réaliser des tests de charge avec batterie pleine et batterie vide.
Pour émuler une batterie vide, nous avons placé 6 diodes en séries de manière à pouvoir émuler une source de tension de 3.6V.
A l’aide de notre module INA, nous avons pu valider les bonnes prises de mesures réalisées par la fuel gauge.
Nous arrivons bien a communiquer en I2C, et a lire les informations dans le moniteur série de l’IDE Arduino.
Le problème maintenant est de vérifier la tension d’entrée du projet car l’intérêt du chargeur de batterie réside tout de même dans la grande plage de tension d’entrées possible.

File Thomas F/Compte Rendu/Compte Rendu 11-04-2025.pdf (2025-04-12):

Compte Rendu 11/05/2025 :

Durant cette séance, nous avons perdu énormément de temps pour tenter de faire fonctionner le DS6521 à des tensions supérieures.
Nos efforts étaient vaincus, puisque visiblement l’erreur vient de la datasheet.
En effet dans la datasheet il est mentionné :

Ce titre serait donc trompeur puisque le composant ne semble pas tolérer des tensions supérieures à 6V.
Nous pouvons vérifier cela dans les lignes qui suivent :

Ces features sont extrêmement floues, nous avions compris que ce composant avec une tension d’entrée maximale de 28V, et une protection sur contre les surtensions de moins de 6V. Mais il s’agirait en réalité de l’inverse d’après nos mesures :
On aurait donc un composant avec une tension d’entrée max de 6V (donc prévu pour des applications 5V tel que des alimentations USB
Et donc on aurait une protection contre les surtensions jusqu’à 28V.
Cette notation trompeuse peut venir du faire que le composant est de fabrication et de conception chinoise, expliquant de possibles erreurs de traduction mais également une documentation peu fournie avec aucun exemple existant en ligne.
Nous nous sommes donc après cela résolu à abandonner l’idée de pouvoir travailler avec des tensions plus élevées que 5V. Ainsi nous allons nous focaliser pour la suite sur la fuel gauge et son fonctionnement.
Cependant, j’ai pu souligner en ramenant le projet chez moi pour réaliser du développement sur l’ESP32 qu’un son aigu persistait lors de la charge.
Après vérification à l’oscilloscope, on a une fréquence parasitaire qui empêche le DS6521 de convertir correctement la tension d’entrée en 4.2V. Cette fréquence se situe autour des 2kHZ et ne provient pas de la source d’alimentation.
J’approfondirai chez moi ce problème en espérant trouver une solution. L’essentiel pour nous est que la fuel gauge fonctionne correctement.

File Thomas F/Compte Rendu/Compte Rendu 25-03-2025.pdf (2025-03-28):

Compte Rendu 25/03/25 :
Assemblage des pcb.
Utilisation des composants smd et du four.
Ajout des connecteurs.
Adaptation du connecteur de la batterie 330mAh (erreur dans le nouveau connecteur, + et – inversés, changement des fils)
Vérification principalement du sens des composants, surtout des diodes.
Vérification du fonctionnement du système.
Erreur aberrante : la résistance R13 vaut 10k, ce qui n’est pas logique car la NTC du DS6521 vaut 10k nominal et est en parallèle avec R12 = 10k aussi. On doit avoir R13 = 5k du coup.
Ajustement en ajoutant une R = 10k en parallèle de R13
Désactivation en reliant la Broche 1 du DS6521 au gnd de la NTC pour la phase de test Remplacement des NTC par des R de 10k pour simuler une valeur moyenne
Le DS6521 s’active bien lorsque Vin vaut 4.5V ou plus.
Problème constaté : lorsque l’on augmente Vin au-dessus de 6V, l’alim grésille et semble se mettre en sécurité, problème au niveau du DS6521 ?
Chip HS ?
Lorsque l’on ne charge pas la batterie, le fuel gauge a l’air d’être correctement allumée, on a bien une tension régulée de 2.5 V
Prochaine séance : vérifier le fonctionnement du DS6521 et voir s’il ne faut pas le changer.

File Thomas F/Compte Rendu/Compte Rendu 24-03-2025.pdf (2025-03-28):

Compte Rendu 24/03/25 :
Réception des pcb du projet, pas d’assemblage ce cours ci faute de composants.

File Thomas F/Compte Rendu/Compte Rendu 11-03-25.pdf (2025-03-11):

Compte Rendu 11/03/25 :
Durant cette séance, nous avons revu le schéma pour améliorer certains points. Le nouveau schéma est le suivant :

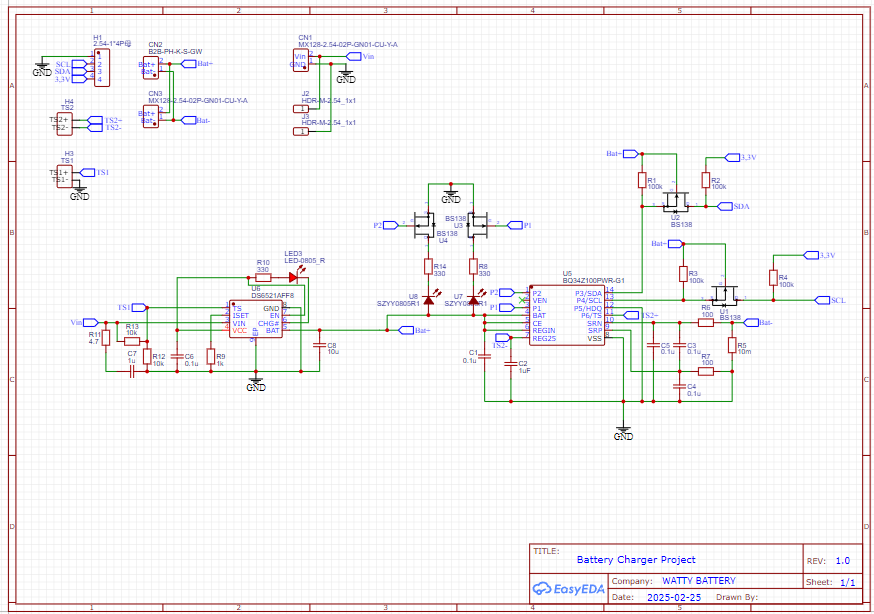
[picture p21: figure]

R11 a été modifiée pour passer de 330 Ohm à 4.7 Ohm (erreur d’inattention vis-à-vis de la datasheet) et une partie de la fuel gauge a été revue par Thomas C.
Ensuite, nous avons pu réaliser le routage final de notre carte présenté ci-dessous :
On peut constater l’importande de la symétrie au niveau de la partie shunt de la fuel gauge qui a été revue de manière à suivre les recommandations de la Datasheet :

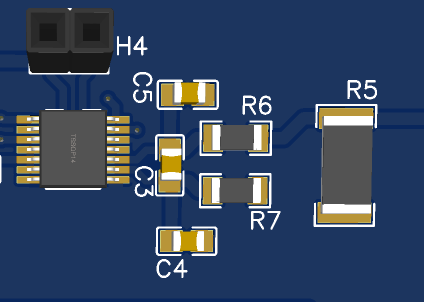
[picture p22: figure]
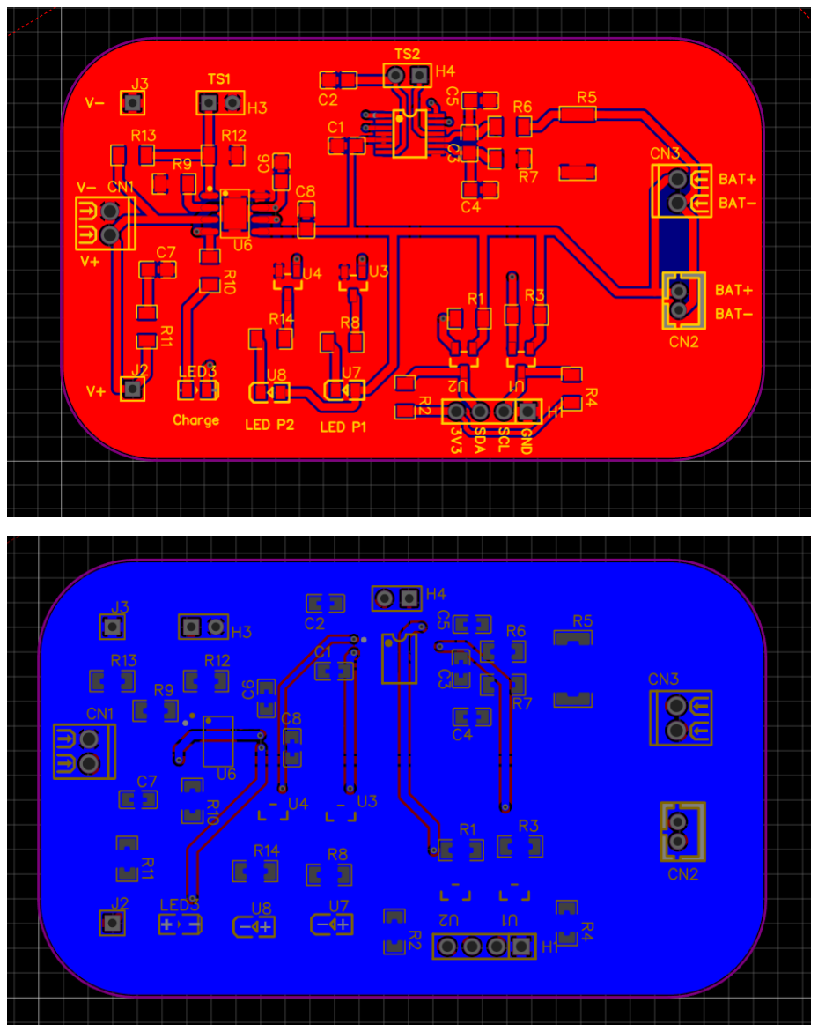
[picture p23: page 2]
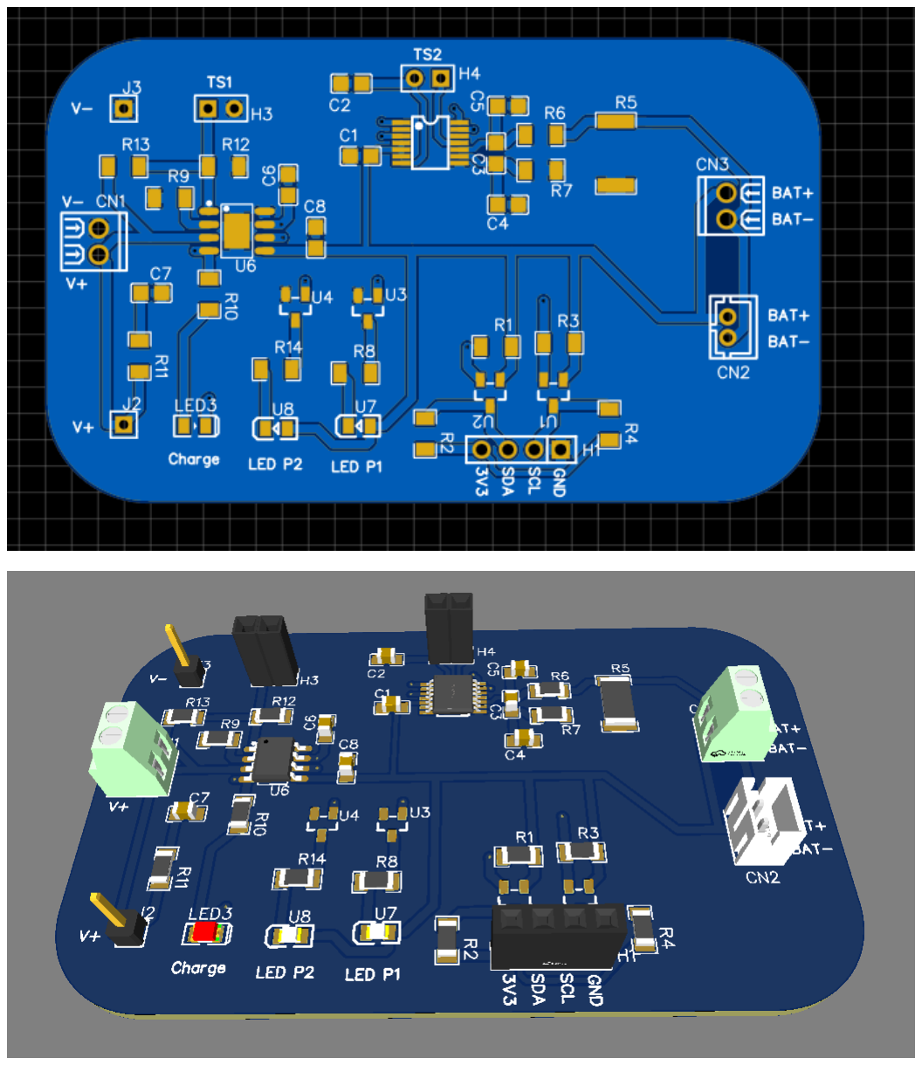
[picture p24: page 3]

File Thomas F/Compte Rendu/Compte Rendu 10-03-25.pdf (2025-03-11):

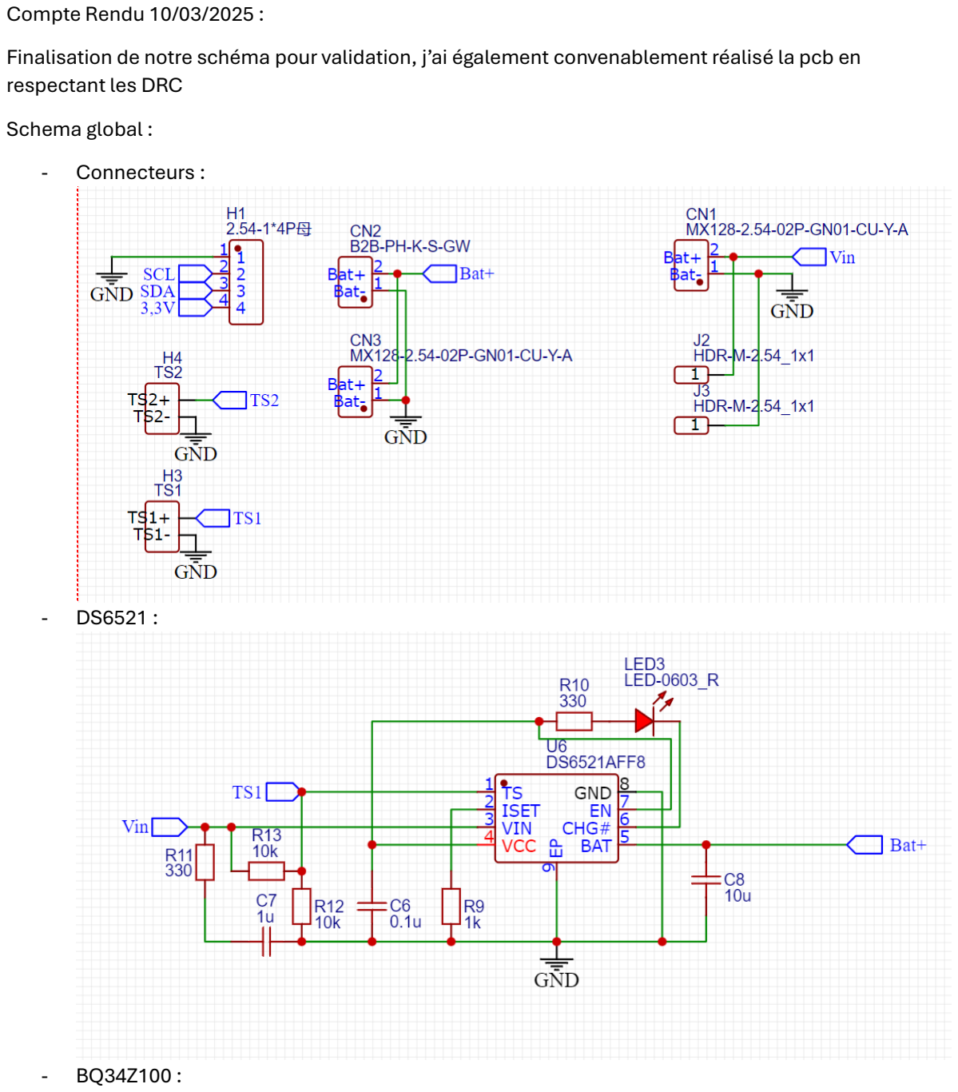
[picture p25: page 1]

Compte Rendu 10/03/2025 :
Finalisation de notre schéma pour validation, j’ai également convenablement réalisé la pcb en respectant les DRC
Schema global :
- Connecteurs :
- DS6521 :
- BQ34Z100 :


Routage :
- Recto :
- Verso :


- DRC :

PCB 2D :


PCB 3D :


Nous attendons la review du schéma pour potentiellement apporter des modifications.

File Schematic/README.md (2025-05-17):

Veuillez Trouver ici l'ensemble des fichiers sources du projet.
Le projet a été exporté au format EASYEDA sous la forme de deux fichiers .json

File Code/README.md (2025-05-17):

## Code C++ pour ESP-32
Gestion de la fuel gauge
Validation avec INA219

________________________
  Placer Ici Le Code
________________________

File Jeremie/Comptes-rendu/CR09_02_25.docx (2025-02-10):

Améliorations du code de lecture de la fuel gauge et de l’INA


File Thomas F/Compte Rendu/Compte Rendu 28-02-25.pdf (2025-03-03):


Compte Rendu de fin de séance
Thomas Faucherre
25/02/25 :
Thomas C a fini le schéma de la fuel gauge
Après avoir réalisé le schéma global, j’ai pu faire le routage de la carte :

On ajoute ensuite les plans de masses recto verso :


Vue 2D :


Vu 3D :


La carte nécessite quelques ajustements notamment au niveau des connecteurs qui seront réalisés pour la prochaine séance.

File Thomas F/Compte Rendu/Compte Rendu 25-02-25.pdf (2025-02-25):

Compte Rendu de fin de séance
Thomas Faucherre
25/02/25 :
Durant cette séance, nous avons pour objectif de réaliser en partie la pcb pour pouvoir l’envoyer en impression le plus rapidement possible. Pour cela Thomas C fini le schéma autour du BQ34 (fuel Gauge).
Ainsi, j’ai pu m’exercer au routage de carte en utilisant Easy EDA.
Voici la partie DS6521 routée :


Le schéma de la fuel gauge n’étant pas terminé, j’ai pu faire un tentative de routage avec le BQ et le DS6521 :


A noter que ce n’est absolument pas la pcb finale, une fois le schéma du BQ validé, nous pourrons terminer le routage.
De plus il y a des revues a faire au niveau de la largeur et de l’épaisseur des pistes.
Ainsi je pense pouvoir réaliser le routage chez moi pour le faire valider à la prochaine séance.

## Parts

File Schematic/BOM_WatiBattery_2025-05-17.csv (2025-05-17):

ID | Name | Designator | Footprint | Quantity | Manufacturer Part | Manufacturer | Supplier | Supplier Part | Price
1 | 0.1u | C3,C1,C4,C5,C6 | C0805 | 5
2 | 10m | R5 | R2512 | 1
3 | 100 | R6,R7 | R1206 | 2
4 | 1uF | C2 | C0805 | 1
5 | 1u | C7 | C0805 | 1
6 | 10u | C8 | C0805 | 1
7 | MX128-2.54-02P-GN01-CU-Y-A | CN1,CN3 | CONN-TH_2P-P2.54_MX128-2.54-GN01-02P-CU-Y-A | 2 | MX128-2.54-02P-GN01-Cu-Y-A | MAX(迈旭) | LCSC | C5188442 | 0.157
8 | B2B-PH-K-S-GW | CN2 | CONN-TH_B2B-PH-K-S | 1 | B2B-PH-K-S-GW | JST | LCSC | C5251182 | 0.124
9 | 2.54-1*4P母 | H1 | HDR-TH_4P-P2.54-V-F | 1 | 2.54-1*4P母 | BOOMELE(博穆精密) | LCSC | C2718488 | 0.046
10 | TS1 | H3 | HDR-F-2.54_1X2 | 1 |  |  | LCSC | C49661 | 0.038
11 | TS2 | H4 | HDR-F-2.54_1X2 | 1 |  |  | LCSC | C49661 | 0.038
12 | HDR-M-2.54_1x1 | J2,J3 | HDR-M-2.54_1X1 | 2 |  |  | LCSC | C81276 | 0.007
13 | LED-0805_R | LED3 | LED0805_RED | 1 | 19-217/R6C-AL1M2VY/3T | EVERLIGHT(台湾亿光) | LCSC | C72044 | 0.021
14 | 100k | R1,R2,R3,R4 | R1206 | 4
15 | 330 | R8,R10,R14 | R1206 | 3
16 | 1k | R9 | R1206 | 1
17 | 4.7 | R11 | R1206 | 1
18 | 10k | R12,R13 | R1206 | 2
19 | BS138 | U1,U2,U3,U4 | SOT23 | 4
20 | BQ34Z100PWR-G1 | U5 | TSSOP-14_L5.0-W4.4-P0.65-LS6.4-BL | 1 | BQ34Z100PWR-G1 | TI(德州仪器) | LCSC | C91302 | 2.493
21 | DS6521AFF8 | U6 | ESOP-8_L4.9-W3.9-P1.27-LS6.0-BL-EP-1 | 1 | DS6521AFF8 | DSTECH(奥简科技) | LCSC | C5884237 | 0.104
22 | SZYY0805R1 | U7,U8 | LED0805-R-RD | 2 | SZYY0805R1 | yongyu(永裕光电) | LCSC | C19712534 | 0.006

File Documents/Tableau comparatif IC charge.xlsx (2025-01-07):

Tableau récapitulatif des Composants de charge
 |  |  |  |  |  |  | bq246xx :
Ref | price | package | battery type | max charge current | number of cells | supply voltage |  | bq24600 | bq24610 | bq24616 | bq24617 | bq24618 | bq24650
LT3650-4.2 | $11.6472 | DFN-12(3x3) | Lithium-ion/Polymer | 2A | 1 cell | 4.75V to 32V | Cell chemistry | Li-lon/Li-Polymer | Li-lon/Li-Polymer | Li-lon/Li-Polymer | Li-lon/Li-Polymer | Li-lon/Li-Polymer | Li-lon/Li-Polymer
MAX20094 | $5.0333 | TQFN-28(5x5) | Lithium-ion/Polymer | 1A | 1 cell | 3.5V to 36V | Number of cells in series (minimum to maximum, 4.2 V/cell) | 1 to 6 | 1 to 6 | 1 to 6 | 1 to 6 | 1 to 6 | 1 to 6
LTC4089 | $4.9546 | DFN-22-EP(3x6) | Lithium-ion/Polymer | 1.2A | 1 cell | 6V to 36V | Charge voltage (minimum to maximum) (V) | 2.1 to 26 | 2.1 to 26 | 2.1 to 26 | 2.1 to 22 | 2.1 to 26 | 2.1 to 26
ISL6293 | $0.8284 | DFN-10(3x3) | Lithium-ion/Polymer | 1A | 1 cell | 4.3V to 28V | Input voltage range (minimum to maximum) (V) | 5 to 28 | 5 to 28 | 5 to 28 | 5 to 24 | 4.7 to 28 | 5 to 28
bq25050 | 1.48 € | WSON (10) | Lithium-ion/Polymer | 1A | 1 cell | 3.55V to 28V | Input overvoltage (V) | 32 | 32 | 32 | 26 | 32 | 32
BQ2404x | 1.05 € | WSON (10) | Lithium-ion/Polymer | 1A | 1 cell | 3.5V to 28V | Maximum battery charging current (A) | 10 | 10 | 10 | 10 | 10 | 10
LTC4091IDJC | 10,640 € | DFN-EP-22 | Lithium-ion/Polymer | 1.5A | 1 cell | 6V à 36V | Switching frequency (kHz) | 1200 | 600 | 600 | 600 | 600 | 600
LT3650EMSE | 7,260 € | MSOP-EP | Lithium-ion/Polymer | 2A | 1 cell | 4,75V à 32V | JEITA charging temperature profile | No | No | Yes | No | No | No
CN3761 | Dispo en classe | 10 Pin SSOP | Lithium-ion/Polymer | 4A | 1 cell | 4.5V to 28V | DPM | No | Iin DPM | Iin DPM | Iin DPM | Iin DPM | Vin DPM
DS6521A | Dispo en classe | SOT-23-6 & ESOP-8 & DFN2x2-10L & DFN2x3-10L & DFN3x3-10L | Lithium-ion/Polymer | 1A | 1 cell | 4.5V to 28V | Package | VQFN | VQFN | VQFN | VQFN | VQFN | VQFN
HY2112 | $ 0.49 | SOT-23-6 | LiFePO4 | - | 1 cell | 1.5V to 20V
HY2110 & HY2111 | 2.05 € | SOT-23-7 | Lithium-ion/Polymer/LIFEPO4 | - | 1 cell | max 20V
HY2113 | 0,18 $ | DFN-1.8*2.0-6L & SOT-23-6 | Lithium-ion/Polymer | - | 1 cell | max 20V
HY2116 | 0,14 $ | DFN-1.8*2.0-6L & SOT-23-6 | Lithium-ion/Polymer | - | 1 cell | max 20V
Série HY21 et HY25 de hycontek non adapté car max 20V
CN3796 |  | eSOP8 | Lithium-ion/Polymer | 2,7 A | 1 cell | 4,5 V-6,5 V
CN3791 | 1.71€ | SSOP10 | Lithium-ion/Polymer | 4A | 1 cell | 4,5 V-30 V
CN3781 | USD 0.6023 | SSOP10 | Lithium-ion/Polymer | 4A | 1 cell | 4,5 V-30 V
DS6522A |  | DFN2x2-8L & DFN3x3-8L | Lithium-ion/Polymer | 1A | 1 cell | max 28V
TP4056 |  | SOP | Lithium-ion/Polymer | 1A | 1 cell | 0.3V～8V
4 possibilités : CN3761, CN3781, CN3791 ou DS6521
Nous disposons d'un DS6521 et d'un CN3761, nous allons donc nous orienter vers ces composants

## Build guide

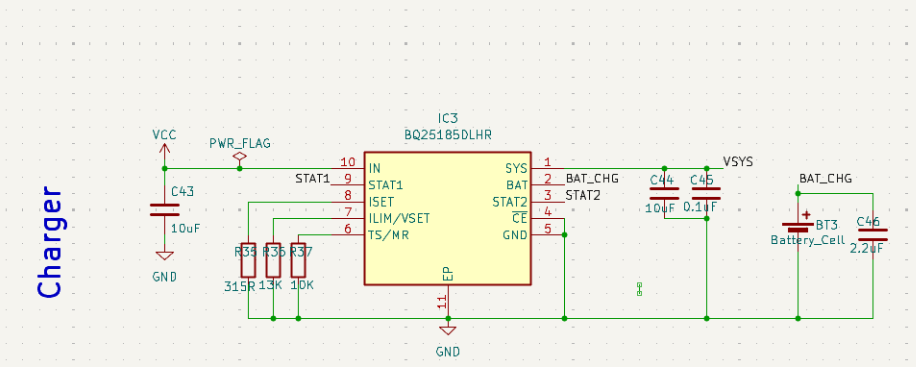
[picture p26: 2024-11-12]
Datasheets/bq25185/montage ex.png

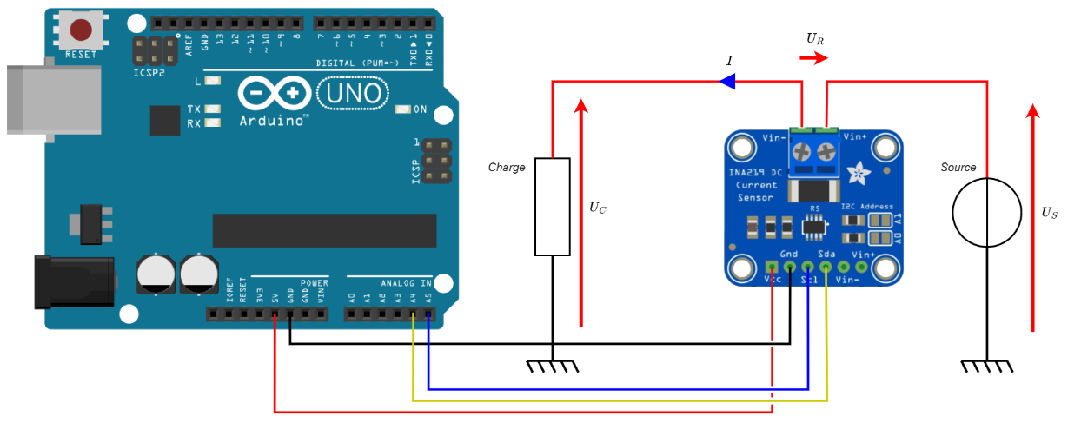
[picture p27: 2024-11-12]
Datasheets/INA219/montage.png

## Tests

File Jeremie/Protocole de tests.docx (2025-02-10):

Protocole de Test pour le Chargeur de Batterie

1. Préparation

1.1 Matériel requis

- Chargeur de batterie
- Batteries compatibles (spécifier type, capacité, tension, chimie, etc.)
- Multimètre
- Thermomètre ou caméra thermique
- Alimentation secteur conforme aux spécifications du chargeur
- Chronomètre
- Ordinateur avec logiciel de suivi (si applicable)
- Carte de test esp32

1.2 Précautions de sécurité

- Vérifier l'intégrité des câbles et connecteurs.
- Porter des équipements de protection (gants, lunettes, etc.).
- S'assurer que les batteries ne sont ni endommagées ni surchargées avant le test.

2. Tests fonctionnels

2.1 Vérification initiale

1. Inspecter visuellement le chargeur pour détecter tout dommage ou défaut.

2.2 Test de connexion

1. Connecter le chargeur à une batterie et à une alimentation secteur.
2. Vérifier la connexion série avec l’interface, et l’allumage de l’écran.

2.3 Test de charge

1. Mesurer la tension et le courant de sortie au début de la charge.
2. Vérifier la durée de la charge jusqu’à la fin, conformément aux spécifications.

2.4 Test de sécurité (Si il y’en a)

1. Simuler une surcharge ou une batterie endommagée et vérifier l'activation des protections.
2. Surveiller les variations de température du chargeur et de la batterie pendant l’utilisation.
3. Tester les protections contre les courts-circuits en sortie.

3. Tests de performance

3.1 Efficacité énergétique

1. Mesurer la consommation du chargeur (entrée) et la puissance délivrée à la batterie (sortie).

3.2 Test de compatibilité

1. Charger différents types de batteries compatibles et vérifier le bon fonctionnement.

3.3 Test de durée

1. Effectuer un test de charge-décharge répétée sur une période prolongée.
2. Observer les variations de performances ou les signes de vieillissement.

4. Rapport de test

1. Documenter les résultats obtenus pour chaque test.
2. Inclure des observations sur les éventuels dysfonctionnements ou écarts.
3. Ajouter des photos/vidéos pertinentes pour compléter les données.

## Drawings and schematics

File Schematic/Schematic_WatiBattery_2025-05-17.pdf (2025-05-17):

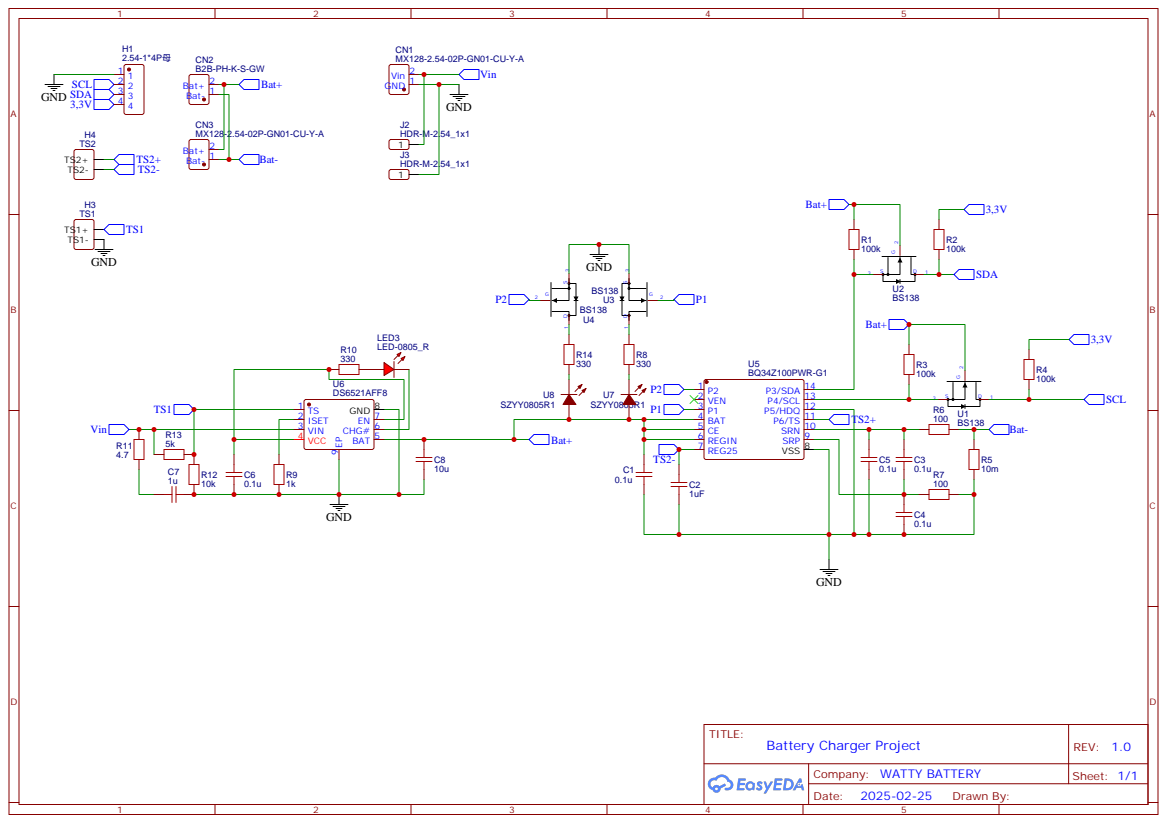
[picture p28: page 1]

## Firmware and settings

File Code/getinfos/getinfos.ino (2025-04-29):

#include <Wire.h>
#include <Adafruit_INA219.h>

#define FUEL_GAUGE_ADDR 0x55

// Commandes I2C de la fuel gauge
#define CMD_STATE_OF_CHARGE 0x02  // État de charge (%)
#define CMD_VOLTAGE         0x08  // Tension (mV)
#define CMD_TEMP            0x0C  // Température (0.1 K)

#define DEBUG true

// Initialisation du capteur INA219
Adafruit_INA219 ina219;

// Variables pour la gestion des intervalles non bloquants
unsigned long previousMillisFuel = 0;
const unsigned long fuelInterval = 5000; // Mise à jour de la fuel gauge toutes les 5000 ms

unsigned long previousMillisCurrent = 0;
const unsigned long currentInterval = 1000; // Mise à jour du courant toutes les 1000 ms

// Envoi d'une commande de contrôle (par exemple IT_ENABLE)
void sendControlCommand(uint16_t subcmd) {
  Wire.beginTransmission(FUEL_GAUGE_ADDR);
  Wire.write(0x00);  // Adresse du registre Control()
  Wire.write(subcmd & 0xFF);         // LSB
  Wire.write((subcmd >> 8) & 0xFF);    // MSB
  Wire.endTransmission();
  if(DEBUG) {
    Serial.print("Commande de contrôle (0x");
    Serial.print(subcmd, HEX);
    Serial.println(") envoyée");
  }
}

// Lecture d'un octet (utilisé pour le SoC)
uint8_t readFuelGaugeByte(uint8_t cmd) {
  Wire.beginTransmission(FUEL_GAUGE_ADDR);
  Wire.write(cmd);
  if(Wire.endTransmission(false) != 0) {
    if(DEBUG) Serial.println("Erreur de communication (byte)");
    return 0xFF;
  }
  Wire.requestFrom(FUEL_GAUGE_ADDR, (uint8_t)1);
  if(Wire.available() < 1) {
    if(DEBUG) Serial.println("Pas assez de données (byte)");
    return 0xFF;
  }
  return Wire.read();
}

// Lecture de 2 octets en format little endian (utilisé pour tension, température, etc.)
uint16_t readFuelGaugeWord(uint8_t cmd) {
  Wire.beginTransmission(FUEL_GAUGE_ADDR);
  Wire.write(cmd);
  if(Wire.endTransmission(false) != 0) {
    if(DEBUG) Serial.println("Erreur de communication (word)");
    return 0xFFFF;
  }
  Wire.requestFrom(FUEL_GAUGE_ADDR, (uint8_t)2);
  if(Wire.available() < 2) {
    if(DEBUG) Serial.println("Pas assez de données (word)");
    return 0xFFFF;
  }
  uint16_t lsb = Wire.read();
  uint16_t msb = Wire.read();
  return (msb << 8) | lsb;
}

// Fonction regroupant les lectures de la fuel gauge
void updateFuelGauge() {
  uint8_t soc = readFuelGaugeByte(CMD_STATE_OF_CHARGE);
  if(soc != 0xFF) {
    Serial.print("Etat de charge : ");
    Serial.print(soc);
    Serial.println("%");
  } else {
    Serial.println("Erreur lors de la lecture de l'état de charge");
  }
  
  uint16_t voltage = readFuelGaugeWord(CMD_VOLTAGE);
  if(voltage != 0xFFFF) {
    Serial.print("Tension (mV) : ");
    Serial.println(voltage);
  } else {
    Serial.println("Erreur lors de la lecture de la tension");
  }
  
  uint16_t temp = readFuelGaugeWord(CMD_TEMP);
  if(temp != 0xFFFF) {
    float temperatureC = (temp * 0.1) - 273.15;
    Serial.print("Température (°C) : ");
    Serial.println(temperatureC);
  } else {
    Serial.println("Erreur lors de la lecture de la température");
  }
  
  Serial.println("-----------------------------");
}



void setup() {
  Serial.begin(115200);
  Wire.begin();

  // Initialisation du capteur INA219
  if (!ina219.begin()) {
    Serial.println("Impossible de trouver le capteur INA219 !");
    while (1);
  }
  Serial.println("Capteur INA219 initialisé avec succès !");
  
  // Délai initial uniquement lors du setup (peut être raccourci si possible)
  delay(300);
  
  // Activation du suivi d'impédance avec IT_ENABLE
  sendControlCommand(0x0021);
  if(DEBUG) Serial.println("Commande IT_ENABLE envoyée.");
}

void loop() {
  unsigned long currentMillis = millis();
  
  // Mise à jour non bloquante de la lecture du courant via INA219
  if(currentMillis - previousMillisCurrent >= currentInterval) {
    previousMillisCurrent = currentMillis;
    float current_mA = ina219.getCurrent_mA();
    Serial.print("Courant (mA) : ");
    Serial.println(current_mA);
  }
  
  // Mise à jour non bloquante des lectures de la fuel gauge
  if(currentMillis - previousMillisFuel >= fuelInterval) {
    previousMillisFuel = currentMillis;
    updateFuelGauge();
  }
}

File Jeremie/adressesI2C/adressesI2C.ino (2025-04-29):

#include <Wire.h>

void setup() {
  Wire.begin();
  Serial.begin(9600);
  while (!Serial); // Attendre que le port série soit prêt (utile pour les cartes comme Leonardo)
  Serial.println("Scan I2C en cours...");
}

void loop() {
  byte erreur, adresse;
  int nb_peripheriques = 0;

  for (adresse = 1; adresse < 127; adresse++) {
    Wire.beginTransmission(adresse);
    erreur = Wire.endTransmission();

    if (erreur == 0) {
      Serial.print("Peripherique I2C trouve a l'adresse 0x");
      if (adresse < 16) Serial.print('0');
      Serial.println(adresse, HEX);
      nb_peripheriques++;
    } else if (erreur == 4) {
      Serial.print("Erreur inconnue a l'adresse 0x");
      if (adresse < 16) Serial.print('0');
      Serial.println(adresse, HEX);
    }
  }

  if (nb_peripheriques == 0)
    Serial.println("Aucun peripherique I2C trouve.");
  else
    Serial.println("Scan termine.");

  delay(5000); // Attendre 5 secondes avant un nouveau scan
}

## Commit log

2024-11-25 Add files via upload
    Dossier de fichiers avec la datasheet et recommandations de Texas Instrument pour ce CI.
2024-11-26 Add files via upload
    fuel gauge circuit schematic
    [WATTY-BATTERY.kicad_sch]
2025-05-18 Reorganisation des fichier Viale
